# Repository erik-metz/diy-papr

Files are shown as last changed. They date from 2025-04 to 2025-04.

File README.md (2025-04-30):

# DIY Powered Air-Purifying Respirator (PAPR)

DIY-PAPR-front

## ⚠️ Disclaimer
This project is provided for educational and informational purposes only. Building and using a DIY powered air-purifying respirator (PAPR) involves significant health and safety risks. The authors and contributors of this repository accept no liability for any injury, loss, or damage resulting from the use or misuse of the information provided herein.

This system is not certified for use in hazardous environments and must not be used as a substitute for professional, tested respiratory protection when safety is critical (e.g., in welding, toxic fumes, or medical settings).

Use at your own risk.

## ℹ️ Info

This open-source project documents the design and construction of a custom **PAPR system** (Powered Air-Purifying Respirator), tailored for:
- **🪵 Woodworkers 🧔‍♂️with beards🧔‍♂️**
- **👨‍🏭 Hobby welders (including stainless steel)**
- **⚛️ Makers, DIYers, and tinkerers**
- Those looking for an affordable alternative to commercial systems like:
  - JSP PowerCap Active IP
  - Optrel Swiss Air
  - 3M Versaflo Series
  - CleanSpace Ultra / CleanSpace Halo
  - Dräger X-plore 8000

---

## 🔧 Features

- 🔋 Powered by **Bosch 18V Professional** battery
- 🌬️ Active airflow via **centrifugal blower** or high-quality fan (Delta, Noctua)
- 🧰 Modular filter support using **standard NATO 40mm** filters (3M, Dräger, etc.)
- 🧱 Custom 3D-printed parts for housing, mask connectors, mounts
- 🎛️ PWM speed control for fan noise & flow balancing
- 🛡️ Designed with options for **welding fumes** protection (e.g. NO, CO, P3)

---

## 📦 Bill of Materials (BOM)

| Component | Description / Example | My Pick |
|---|---|---|
| Filter | 3M DT-1135E or Dräger 6738801 (NATO 40mm) | 3M DT-1135E 7100260628 |
| Fan / Blower | Delta BFB1012M or equivalent centrifugal blower | Delta BFB1012M-BG51R |
| Power source | Bosch 18V Li-ion (with 3D-printed battery holder) |
| Buck converter | Step-down 18V → 12V (min. 2A recommended) |
| PWM generator | DC 12V PWM Sspeed Ccontroller |
| Mask interface | Optrel Swiss Air replacement mask (or custom design) | §M 6200
| Hose | Anti-static flexible hose (like CPAP) |
| Enclosure | 3D-printed case or laser-cut design for fan & filter |

---

## 🧪 Filter Options

| Filter | Standard | Suitable For | Notes |
|---|---|---|---|
| 3M DT-1135E 7100260628 | P3 PSL R D | Wood dust, fumes | Affordable, easy to get |
| 3M DT-4045 7100260628  | A2B2E2K2 P3 PSL R D | Welding (incl. stainless), VOCs, ammonia | Broad gas protection, reusable |
| Dräger 6738797 | A2B2E2K2 P3 Hg R D  | Welding (incl. stainless), mercury, ammonia | Industrial-grade, high protection |
| Dräger 6738815 | A2B2E2K1 P3 Hg R D  | Welding fumes, mercury, organic gases | Similar to 6738797, slightly less ammonia rating |

I picked the 3M DT-1135E 7100260628 since I will mainly dow oodworking with it

---

## Fan

I picked the Delta BFB1012M-BG51R since it was cheap and available on ebay

Dimensions: Height: 97 mm Depth: 94 mm Width:33 mm
AC/DC: DC Blower Fan
Voltage: DC 12V
Working Voltage: 6.0-13.2V
Power: 5.8W
Current: 0.48A
Speed: 3200 RPM
Air Flow 27.4 CFM (0.78 m3/min)
Pressure Type:  0.893 in H2O
Noise: 52.5 DBA
Red Wire: Positive (+)
Black Wire: Negative (-)
Yellow Wire: PWM
Blue Wire: Tacho
Pulses: 2 per revolution
Re-Ozone depleting substances: no containing PBBs, PBBOs, DFCs, PBBEs, PBDPEs and HCFCs
Preferred duty point of the fan: 25kHz

---

## 🧱 3D-Printed Parts

- 🔌 NATO 40mm to hose adapter
- 🔋 Bosch 18V battery mount
- 💨 Fan mount / filter box
- 🎭 Mask-to-hose interface

All files will be added under `/hardware`.

---

## 📷 Example Images & Diagrams

### Rendering
DIY-PAPR-front
DIY-PAPR-back
DIY-PAPR-inner

### First Batch



---

## 💡 Ideas & Improvements

- Add air pressure monitoring / flow sensor
- CO/NO sensor warning LED for welding use
- Airflow splitter for dual filters
- Replaceable filter gaskets
- Soft shoulder/backpack harness

---
## 🙌 Contributing

Have improvements, 3D models, or test results?  
Please open an issue or pull request — let's build a better and more accessible PAPR together!

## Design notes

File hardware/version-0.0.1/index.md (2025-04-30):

# Version 0.0.1

This initial version consists of two main components: the Fan-Body.stl and the Power-Part.stl. These parts are assembled using two M4 screws and a small amount of CA glue for added stability.

The Hose-connector.stl is printed separately in a vertical orientation to enhance strength and durability. The 40mm-NATO-connector.stl is attached to the Fan-Body.stl using four M4 screws. While it can also be glued, it's intentionally screwed in to simplify the Fan-Body.stl print and to allow for easy replacement—potentially with a bayonet-style connector in future iterations.

The Power-Part is designed to be modular and will be updated to support batteries from other brands such as Makita, Metabo, Milwaukee, and more.

For 3M masks like the 6200 you can add a bayonet cover like this one from [Přemek Marek](https://www.printables.com/model/150650-shigematsu-bayonet-cover-zatka-na-bajonet-shigemat/files), Further to connect the hose to the 3M mask you can use this connector from [tygunn](https://www.thingiverse.com/thing:4605251).

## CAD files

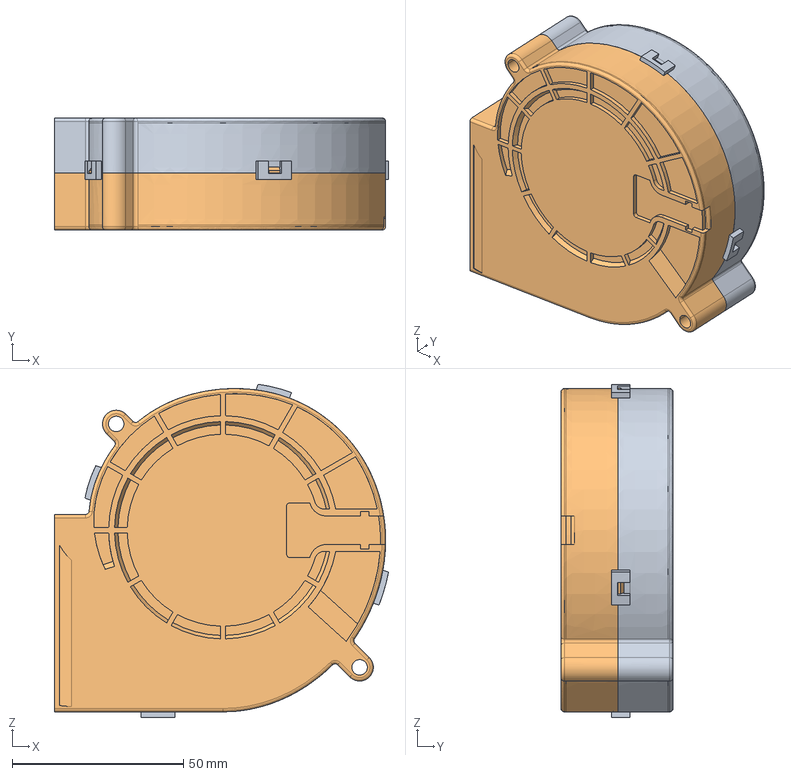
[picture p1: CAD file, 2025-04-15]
hardware/Fan.stp
97.4 x 32.7 x 97.3 mm

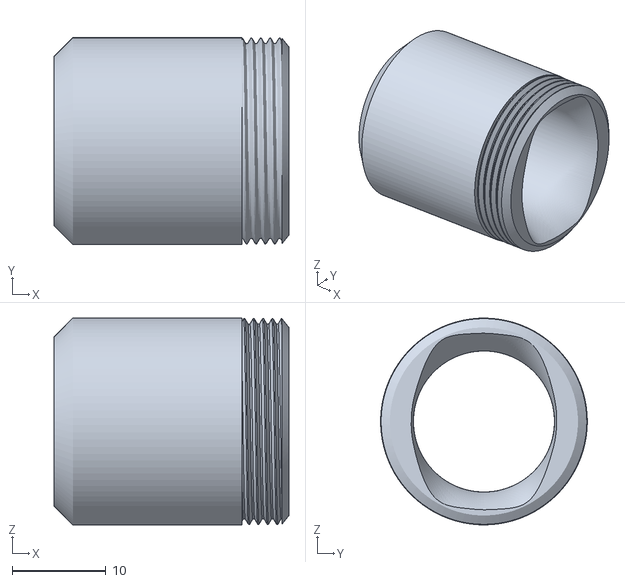
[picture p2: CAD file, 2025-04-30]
hardware/version-0.0.1/Hose-connector.stl
25.0 x 22.0 x 22.0

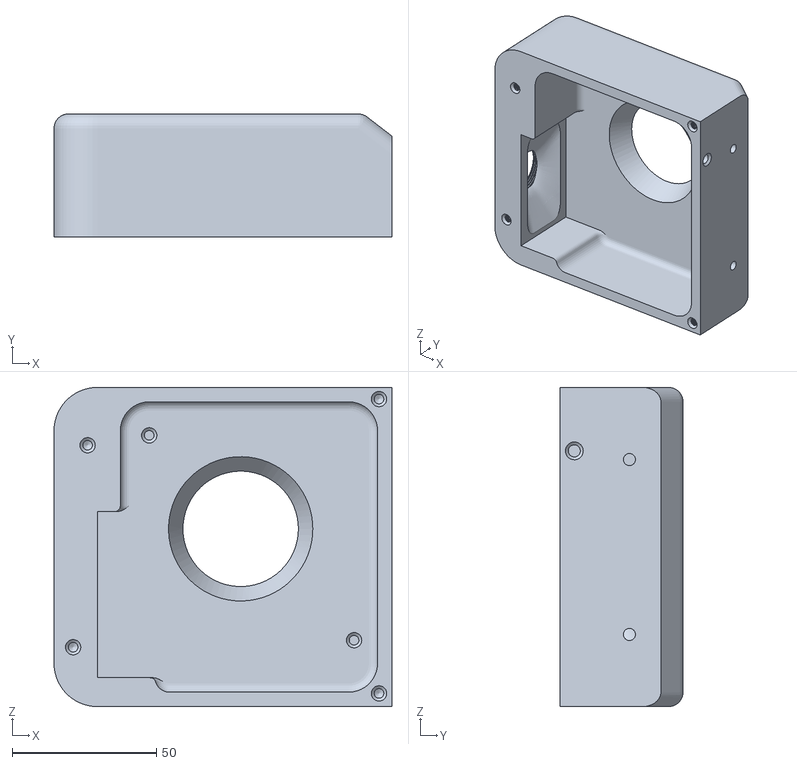
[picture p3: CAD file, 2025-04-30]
hardware/version-0.0.1/Fan-Body.stl
117.1 x 42.7 x 110.6

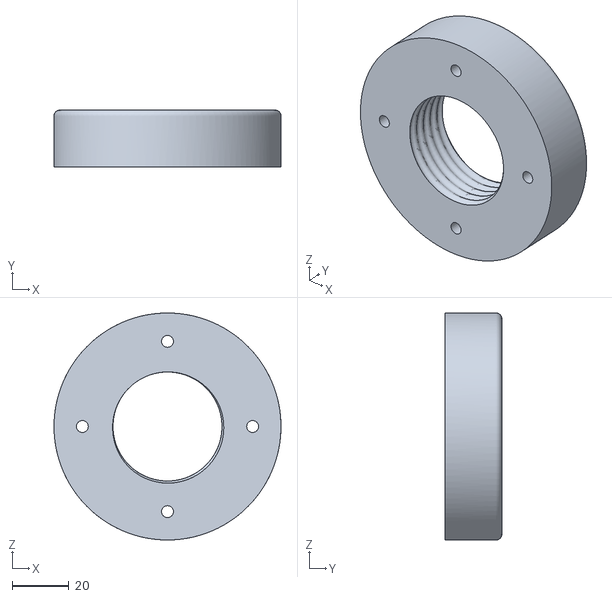
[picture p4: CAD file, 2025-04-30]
hardware/version-0.0.1/40mm-NATO-connector.stl
80.0 x 20.0 x 80.0

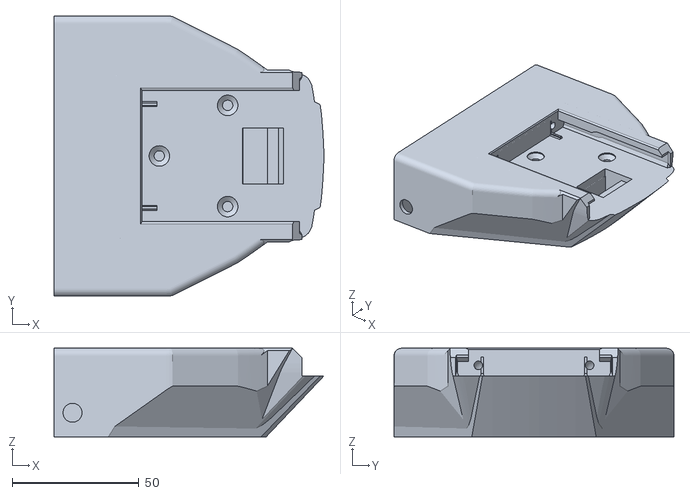
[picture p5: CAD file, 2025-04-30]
hardware/version-0.0.1/Power-Part.stl
106.6 x 110.6 x 35.0

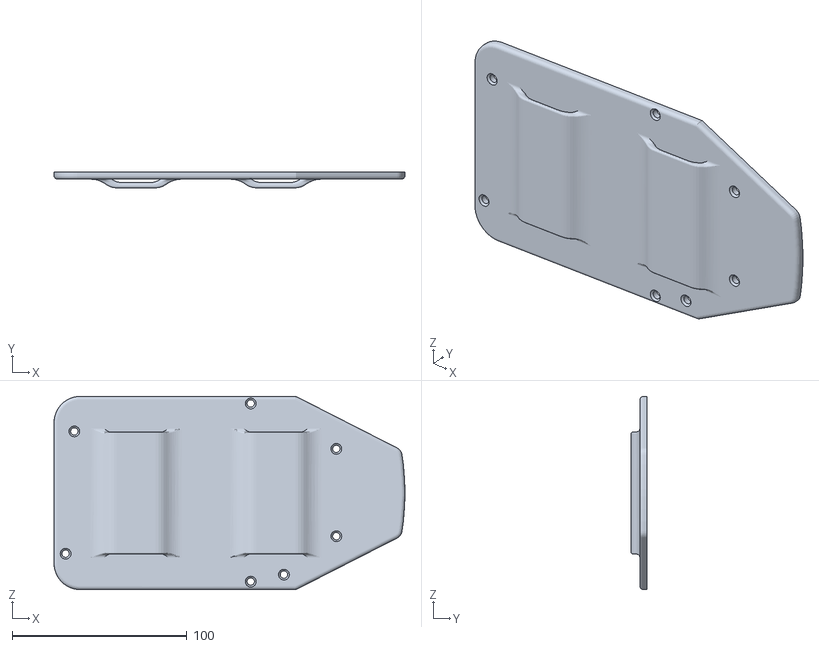
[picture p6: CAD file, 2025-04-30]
hardware/version-0.0.1/lid.stl
201.0 x 9.00 x 110.6

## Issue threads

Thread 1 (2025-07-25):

CAD source files

lynaghk, 2025-07-25:
Thanks for sharing your project --- I was looking into designing myself a powered respirator for woodworking and thrilled to find such a well-documented project.

Would you be willing to share your source CAD files? If not the actual source files, having STEP files would be easier to import+modify in other CAD programs compared to STL. STEP can also be sliced natively by, e.g., OrcaSlicer with better resolution and performance since there's more geometric information (e.g., actual curves rather than just polylines like STL).

erik-metz, 2025-07-28:
@lynaghk thank you for your comment. Since this is an open source project I'm happy to share the files! Since Github only allows 25MB per file I will add a link to the file in the docu and for your conveniece here: [DIY-PAPR.step](https://knlj28ehyr.ufs.sh/f/RpAbILExpGTVZ8VlC3QglRmrndTP9EuLxevt8bQG5H260jos). If you want to constribute later with your changes, please do not hesitate to inform me.

Just a side note I'm currently using this PAPR literally every day. With my big beard 🧔‍♂️ it is so good to get clean fresh air.

erik-metz, 2025-07-29:
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

Awesome! Some parts are not created by me, I just imported them. But I design in Fusion 360
